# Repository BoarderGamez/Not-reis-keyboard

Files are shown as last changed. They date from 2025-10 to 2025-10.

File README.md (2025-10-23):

# The Not Reis Keyboard
A split reversable somewhat 40% column staggered keyboard with more keys than normal. The pinky keys are staggered away from the normal layout to be more ergonomic. Aditionally there is an extra row of macro keys to the very end of the keyboard for more productivity. Inspired by Lukas Reis [40ish% keyboard](https://github.com/capitaoananas/40-ish-split-keyboard/) (Also I made it with him lol) 


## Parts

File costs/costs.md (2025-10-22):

# So, here are the costs for the keyboard (incl all costs eg shipping)
Switch	26,11 dollars or	22. 40 euros
Aliexpress components	30.13 euros	
JLCPCB	16.76 euros	
Total:  69.29 euros	or 80.46 dollars.

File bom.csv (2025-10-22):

Item | Quantity | Unit Price Euros | Total Price Euros | Running Cost Euros excl shipping | Running cost euros incl shipping | Shipping cost | Running Cost Usd | Link
1N4148 Do35 Diode | 44 | 0.021 | 2.1 | 2.1 | 2.1 | 0 | 2.436 | https://nl.aliexpress.com/item/1005010146177612.html
Kailh Hotswap Socket | 44 | 0.075571429 (discount) | 5.29(discount) | 7.39 | 7.39 | 0 | 8.5724 | https://nl.aliexpress.com/item/1005007476614771.html
Usb C Type C31 M14 | 1 | 1.69 | 1.69 | 9.08 | 13.62 | 4.54 | 15.7992 | https://nl.aliexpress.com/item/1005001604876458.html
DSA 1U Blank grey Keycaps | 32 | 0.26475 | 10.59 | 19.67 | 24.21 | 0 | 28.0836 | https://nl.aliexpress.com/item/1005002976015114.html
DSA 1U Blank Blue Keycaps | 8 | 0.371 | 3.71 | 23.38 | 27.92 | 0 | 32.3872 | https://nl.aliexpress.com/item/1005002976015114.html
DSA 1.5U Blank White keycaps | 4 | 0.5675(discount) | 2.27(Discount) | 25.65 | 30.19 | 0 | 35.0204 | https://nl.aliexpress.com/item/4001241957677.html?
Akko Penguin Switches | 44 | 0.31089 | 15.63 | 41.28 | 52.73 | 6.91 | 61.1668 | https://en.akkogear.com/product/akko-v3-pro-penguin-switch-silent/
Pcb Manufacturing | 1 | 9.12 | 9.12 | 50.4 | 69.89 | 8.04 | 81.0724 | https://jlcpcb.com/

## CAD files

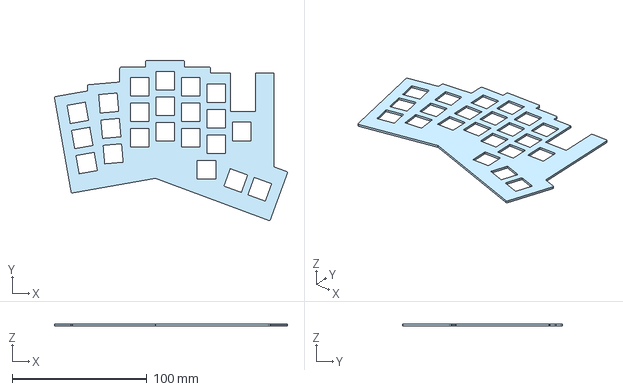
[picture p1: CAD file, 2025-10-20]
Top cover.step
172.6 x 118.5 x 1.50 mm

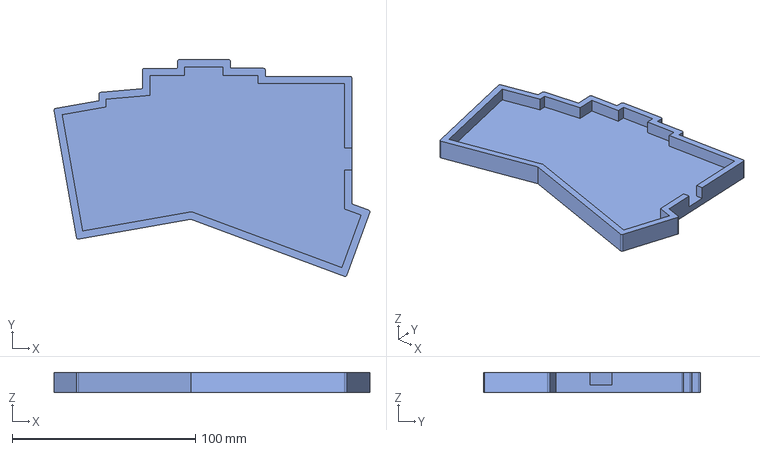
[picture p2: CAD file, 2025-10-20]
bottom part.step
172.6 x 118.5 x 11.0 mm

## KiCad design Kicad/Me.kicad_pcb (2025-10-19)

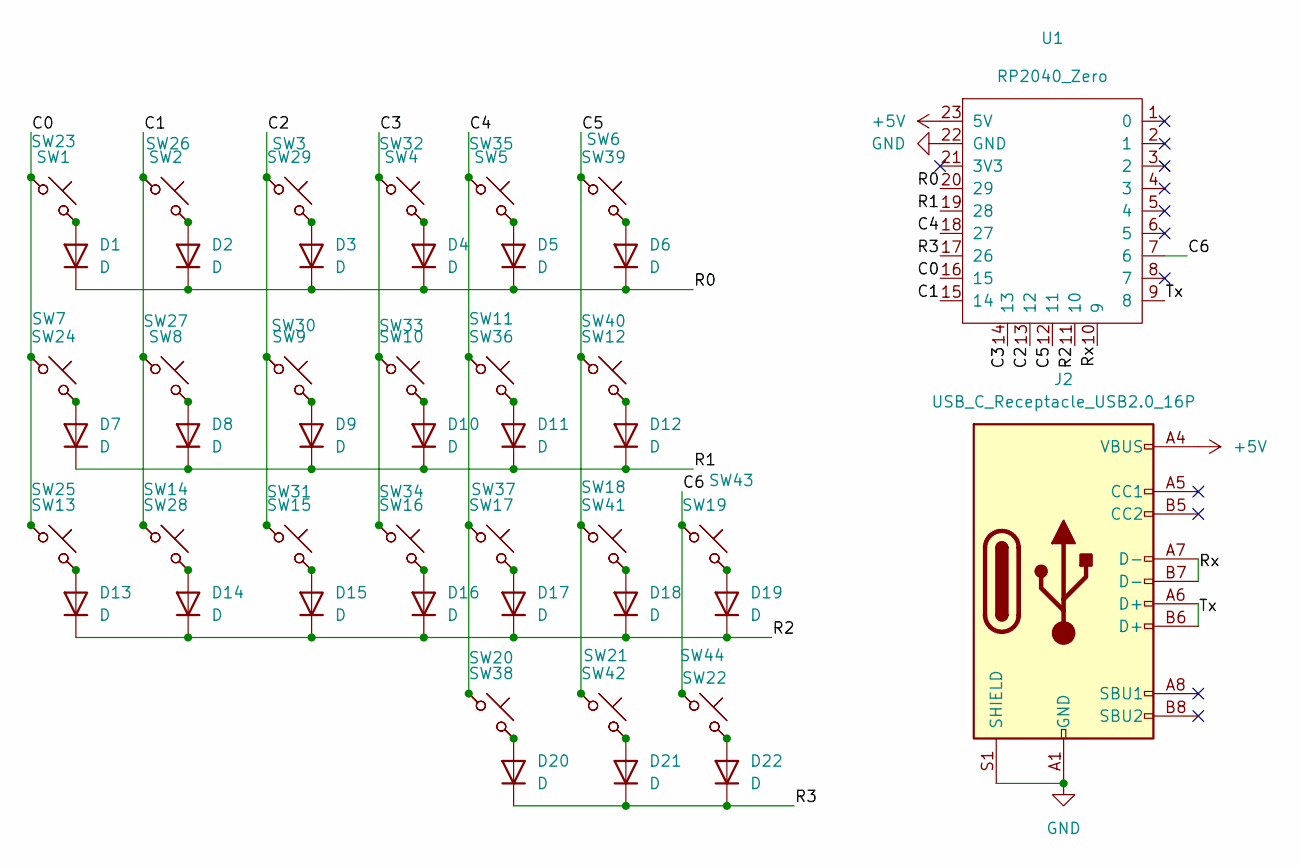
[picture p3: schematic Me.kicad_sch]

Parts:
D1, D2, D3, D4, D5, D6, D7, D8, D9, D10, D11, D12, D13, D14, D15, D16, D17, D18, D19, D20, D21, D22: D; Diode_DO-35
J2: USB_C_Receptacle_USB2.0_16P; USB_C_HRO_TYPE-C-31-M-14
SW1, SW2, SW3, SW4, SW5, SW6, SW7, SW8, SW9, SW10, SW11, SW12, SW13, SW14, SW15, SW16, SW17, SW18, SW20, SW23, SW24, SW25, SW26, SW27, SW28, SW29, SW30, SW31, SW32, SW33, SW34, SW35, SW36, SW37, SW38, SW39, SW40, SW41: SW_Push_45deg; MX-Hotswap-1U
SW19, SW21, SW22, SW42, SW43, SW44: SW_Push_45deg; MX-Hotswap-1.5U
U1: RP2040_Zero

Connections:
+5V: J2.A4 (VBUS), J2.A9 (VBUS), J2.B4 (VBUS), J2.B9 (VBUS), U1.23 (5V)
/C0: SW1.1, SW7.1, SW13.1, SW23.1, SW24.1, SW25.1, U1.16 (15)
/C1: SW2.1, SW8.1, SW14.1, SW26.1, SW27.1, SW28.1, U1.15 (14)
/C2: SW3.1, SW9.1, SW15.1, SW29.1, SW30.1, SW31.1, U1.13 (12)
/C3: SW4.1, SW10.1, SW16.1, SW32.1, SW33.1, SW34.1, U1.14 (13)
/C4: SW5.1, SW11.1, SW17.1, SW20.1, SW35.1, SW36.1, SW37.1, SW38.1, U1.18 (27)
/C5: SW6.1, SW12.1, SW18.1, SW21.1, SW39.1, SW40.1, SW41.1, SW42.1, U1.12 (11)
/C6: SW19.1, SW22.1, SW43.1, SW44.1, U1.7 (6)
/R0: D1.1 (K), D2.1 (K), D3.1 (K), D4.1 (K), D5.1 (K), D6.1 (K), U1.20 (29)
/R1: D7.1 (K), D8.1 (K), D9.1 (K), D10.1 (K), D11.1 (K), D12.1 (K), U1.19 (28)
/R2: D13.1 (K), D14.1 (K), D15.1 (K), D16.1 (K), D17.1 (K), D18.1 (K), D19.1 (K), U1.11 (10)
/R3: D20.1 (K), D21.1 (K), D22.1 (K), U1.17 (26)
/Rx: J2.A7 (D-), J2.B7 (D-), U1.10 (9)
/Tx: J2.A6 (D+), J2.B6 (D+), U1.9 (8)
GND: J2.A1 (GND), J2.A12 (GND), J2.B1 (GND), J2.B12 (GND), J2.S1 (SHIELD), U1.22 (GND)
unnamed: D1.2 (A), SW1.2, SW23.2
unnamed: D2.2 (A), SW2.2, SW26.2
unnamed: D3.2 (A), SW3.2, SW29.2
unnamed: D4.2 (A), SW4.2, SW32.2
unnamed: D5.2 (A), SW5.2, SW35.2
unnamed: D6.2 (A), SW6.2, SW39.2
unnamed: D7.2 (A), SW7.2, SW24.2
unnamed: D8.2 (A), SW8.2, SW27.2
unnamed: D9.2 (A), SW9.2, SW30.2
unnamed: D10.2 (A), SW10.2, SW33.2
unnamed: D11.2 (A), SW11.2, SW36.2
unnamed: D12.2 (A), SW12.2, SW40.2
unnamed: D13.2 (A), SW13.2, SW25.2
unnamed: D14.2 (A), SW14.2, SW28.2
unnamed: D15.2 (A), SW15.2, SW31.2
unnamed: D16.2 (A), SW16.2, SW34.2
unnamed: D17.2 (A), SW17.2, SW37.2
unnamed: D18.2 (A), SW18.2, SW41.2
unnamed: D19.2 (A), SW19.2, SW43.2
unnamed: D20.2 (A), SW20.2, SW38.2
unnamed: D21.2 (A), SW21.2, SW42.2
unnamed: D22.2 (A), SW22.2, SW44.2

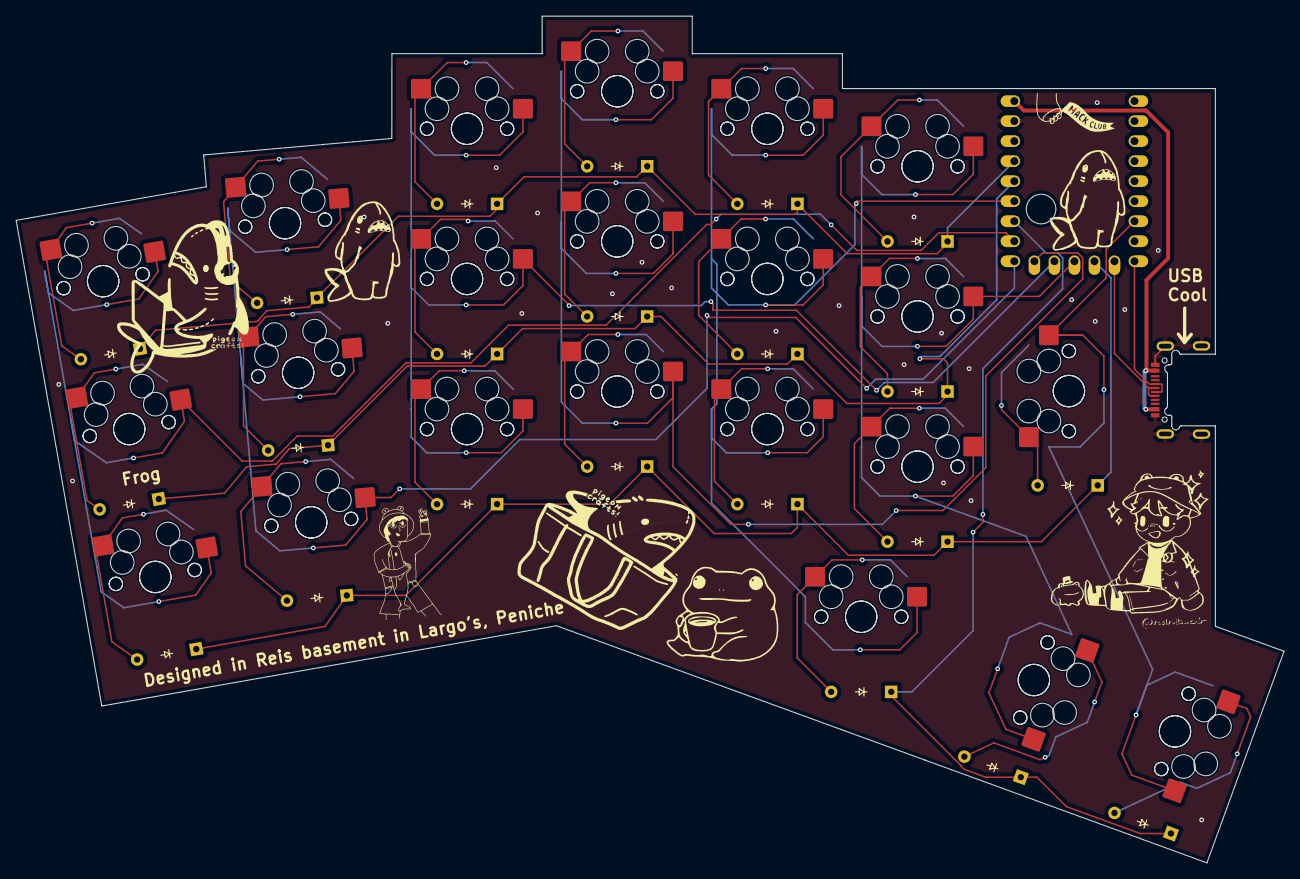
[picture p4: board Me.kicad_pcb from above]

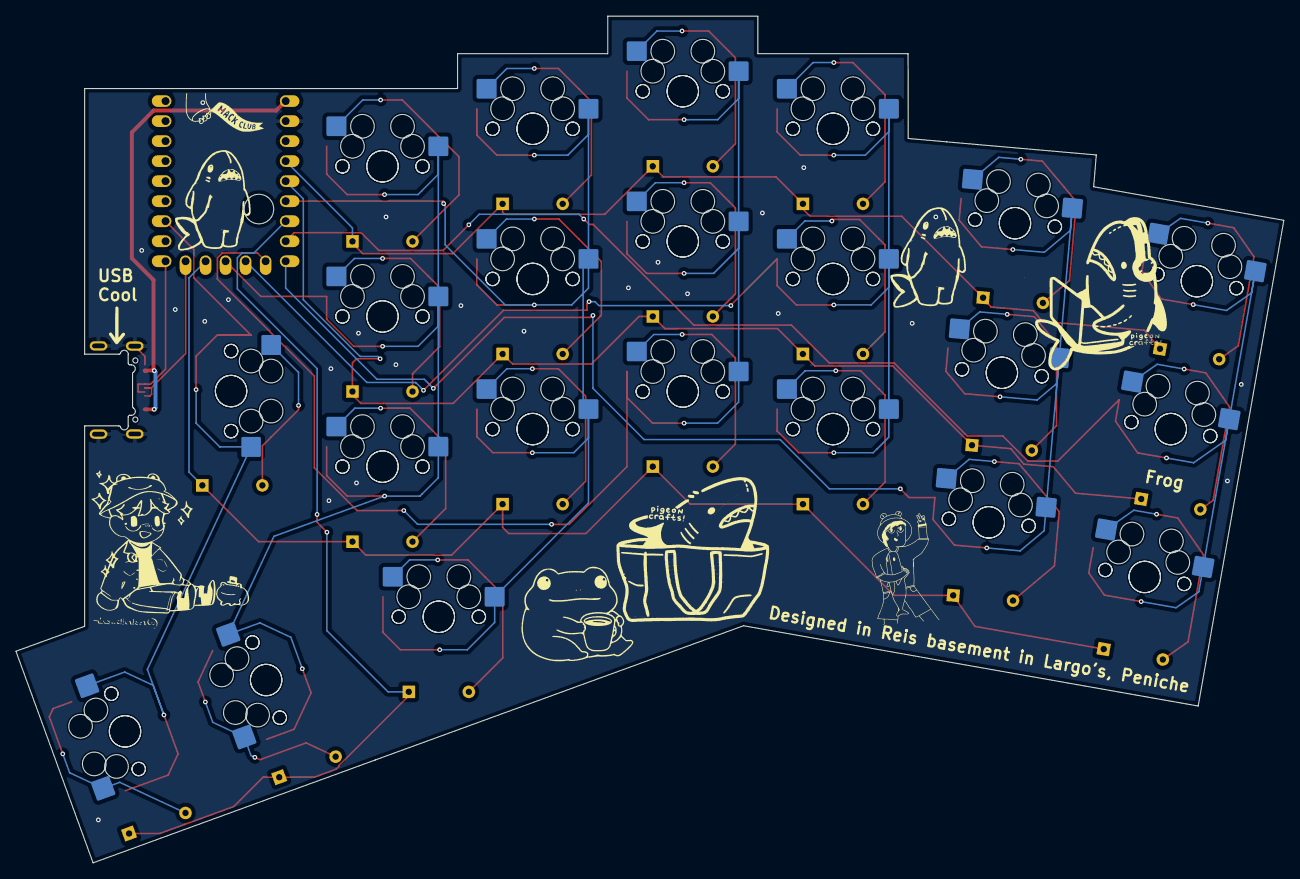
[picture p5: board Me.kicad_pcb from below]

Board: 2 copper layers, 160.9 x 107.4 mm, 68 parts (22 on the bottom side), 37 nets.

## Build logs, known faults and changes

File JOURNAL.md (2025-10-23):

<!--
  ===================    !!READ THIS NOTICE!!   ====================
  DO NOT edit this file manually. Your changes WILL BE OVERWRITTEN!
  This journal is auto generated and updated by Hack Club Blueprint.
  To edit this file, please edit your journal entries on Blueprint.
  ==================================================================
-->

## 10/17/2025 - Started on the keyboard (Almost) Finished the schematics  

So today I started on the schematic for my keyboard. Firstly I decided to make it 40% because, even with nvim it is a lot of work to press the number keys which is a waste of time. Which is why I decided on 40% with 8 modifier keys, 4 on each side. There are some other decisions I made for the keyboard:

- Split: To enhance my productivity and make it ergonomic and get no wrist pain
- Reversable PCB: To make the pcb cheaper to produce (only one pcb), so that I can spend more money on high quality parts and finish.
- Wired: To me wireless keyboards etc are a quite a hassle, charge them, turn them on and connecting bluetooth. Which is why I went for a wired keyboard as it is simple, plug it in, and it works.

I plan to add backlight and hotswap but I'm not at that point yet.

  

## 10/18/2025 - Perfected the layout  

So I was not feeling like working on the pcb, which is why I decided to finalise the layout of the keyboard. So, there were many decisions which I made to get to the current layout:

- Thumb cluster. In the schematics I already decided on 3 keys in the thumb cluster. (As if I put 4+ I wouldn't use all those keys.) But I had to figure out the placement of the thumb keys. So What I did is I went on youtube and looked at split keyboard thumb clusters. For the thumb cluster I decided to have something similar to the scotto keebs [ScottoFly](https://scottokeebs.com/blogs/keyboards/scottofly-handwired-keyboard). 3 keys in thumb's reach. But I also saw a keyboard in a video from ajackster whith 2 2U keys in the thumb cluster, So I took that Idea and put it in the design. And in the end I got 2 1.5U Keys and a 1U key for the thumb cluster
- Pinky area. Unlike other fingers, pinkies are much more angled than other fingers, which is why I rotated the pinky keys by 10 degrees to reduce pinky strain.
- Macro keys. I decided to implement 4macro keys on the keyboard for efficiency. One near the index finger and 3 at the pinky. Macro keys are very versatile and are usefull for efficiency.
PS: It took 1h 20m because I went through many iterations and watched many youtube videos at the same time to find the optimal layout for my hand shape.


## 10/19/2025 11:41 AM - Almost finished routing  

So I spent a LOT of time working on the project so I'm gonna write it step by step to make it more cohesive.

- Perfected the schematics: I changed what the location of connections in the schematic to make routing easier. For example I move the Usb C Tx and Rx connections closer to the actually Usb port on the microcontroller to make it more simple for wiring. 
- Asigned footprints: I picked what components I was gonna use on my keyboard. For the switches I picked the standard mx style hotswap switches for greater customisability and versatility. For the usb port I picked a Usb C port that's pretty much in the middle of the PCB as my pcb is reversable.
- Organised all the components in the pcb: After routing this step took the most amount of time. As my Pcb is reversable I have to get all components double and put them on top of eachother and flip them. This has to be done exactly or the Pcb would not work properly, this is why it took me so long, I had to mess a lot with Origin point and kicad rotation, which is a pain to do becaue my pinky keys are staggered. Furthermore I finished the pcb outline which took me a long time as I tried to find different iterations of the pcb untill it worked.

Screenshot 2025-10-18 210619.png

- Next, routing. This by far was the longest step of making the pcb as I had to route about 100 things AND make it pretty. Unfotunetly I do not have a screenshot for this even but you have to believe me. I ended that day with about the pcb being half routed. It took a long time because I had different rotations and I didn't want my pcb to look like cracked glass like some pcbs so it took hours.
PS: I wrote this the day after which is why so many journal in conjunction  

## 10/19/2025 11:54 AM - Finished the pcb fully  

So today I finished the entire pcb + art. At the start of the day I had only a half finished pcb (as in routing) so I did the following things:

- Finished the routing of the pcb: This morning I came in, to Lukas Reis basement and I finished routing the keyboard. This took a long time as I wanted to make the traces look nice and not like cracked glass.  

- Art: I put in very aesthetic art to make the keyboard more appealing. This was annoying because I have a double sided keyboard and I have to make reversed copies of those to make it work on both sides. Also ground layer! Here it is: 

## 10/19/2025 12 PM - Put in 3d models   

So basically the Kicad 3d viewer was just the pcb and the hotswap sockets, I did not like this so I put in every switch model manually for each switch, this was an annoying process as you had to do them INDIVIDUALLY and you couldn't do it en masse. which SUCKs 


## 10/19/2025 6 PM - Finished the case  

So today I started on the case for the Thingy, but the issue is that I didn't finish because I had a flight. But a stroke of luck came YEY my flight got delayed so I had sufficient time to completely finish the case, it seems to work but only after Ill build it ill see if it works.


## 10/23/2025 - It's FINISHED  

So Here's what I did I first **broke my wrist so this is gonna be short**. But real quick what I did.
Finalised readme
Added screenshots of the pcb with the case together in 3d.
I submitted.
AND ITS DONEs


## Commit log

2025-10-19 cover plate 3d print
    [Cover plate (Left, Flip To make it right).step]
2025-10-19 Finished bottom
    [Bottom part of Frog Keyboard (left side mirror for Right side).step]
2025-10-20 Added cad files
    [Top cover.step, bottom part.step]
2025-10-20 Added schematics
    [Me.kicad_pcb, Me.kicad_sch]
2025-10-20 Added bill of materials
    [BOM-Me.csv]
2025-10-20 changed name
    [bom.csv]
2025-10-22 Added bom
    [BOM-Me.csv]
2025-10-22 Update and rename BOM-Me.csv to bom.csv
    [bom.csv]
